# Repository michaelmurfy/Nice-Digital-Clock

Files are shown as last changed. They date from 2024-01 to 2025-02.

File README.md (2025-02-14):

# Digital Clock Hardware
This is a fork from the original project with 3 main goals:
- Fix automatic DST time.
- Add the ability to change the NTP server.
- Smoother automatic brightness.

I also recreated the web interface to be a little cleaner using Bootstrap. Functionality remains the same outside of that.

## Notice:
There is a hardware change between the 8 clocks sold on Tindie and these. The original production clocks from tindie are:  
- Missing a copper trace between the 3v3 line and the 3v3 output of the LDO. This is corrected with a hand-assembled solder bridge.  
- The I2C lines are shifted right by one pin. The tindie version uses GPIO21 for SDA and GPIO33 for SCL.  
- The Tindie clocks have a manually soldered bodge to move one of the binary coded digits off GPIO 46, which is an input only strapping pin.

## Description
This is an internet connected Clock which synchronizes with NTP servers to perpetually serve an accurate time. It is unable to keep very good time by itself. As such, it requires a stable, consistent network connection to show reliable time. With that, it should always be acctute within a second or so. To improve accuracy, you could modify the firmware to check every hour or half hour instead of once per day.  

It's built using BCD Decoders and 1.5" Seven segment displays for a nice clean look. It also utilizes an ambient light sensor to automatically brighten and dim to match the room light.  

This clock serves it's own webpage for configuration. Upon first boot, it activates an access point ssid `NiceClock`, password `MinesBigger`. Connect to the default gateway `192.168.4.1` to configure the clock and provide network credentials. Once credentials are provided, it should instantly connect and acquire the network time.  
To view the device's IP address, press the boot button on the rear.

## Hacking
This device openly exposes both a TTL UART and JTAG port on the rear of the board, near the ESP Module. You can also use the USB Port to program and upload code. While holding the boot button, then press reset. This enters the ESP32 into bootloader mode, and allows you to reflash new firmware or filesystem to the device.

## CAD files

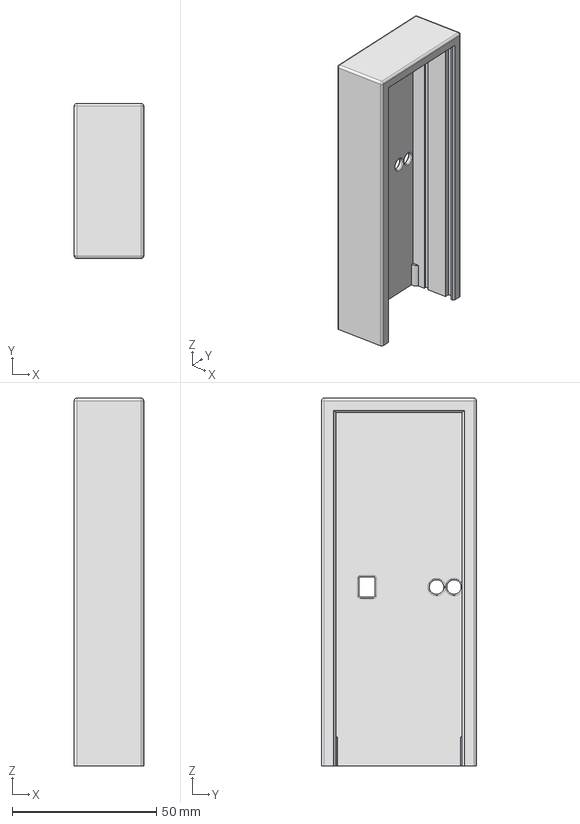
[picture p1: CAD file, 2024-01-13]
Case/V2.1 Case.stp
24.1 x 53.8 x 127.5 mm

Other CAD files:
Case/V2.1 Case.ipt
Case/V2.1 Case.stl

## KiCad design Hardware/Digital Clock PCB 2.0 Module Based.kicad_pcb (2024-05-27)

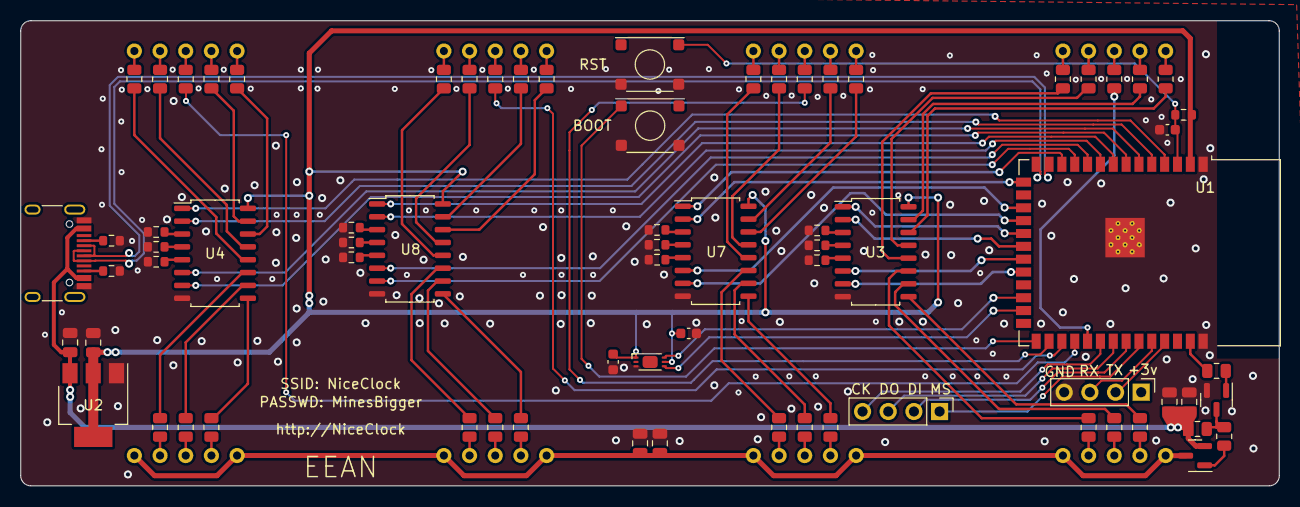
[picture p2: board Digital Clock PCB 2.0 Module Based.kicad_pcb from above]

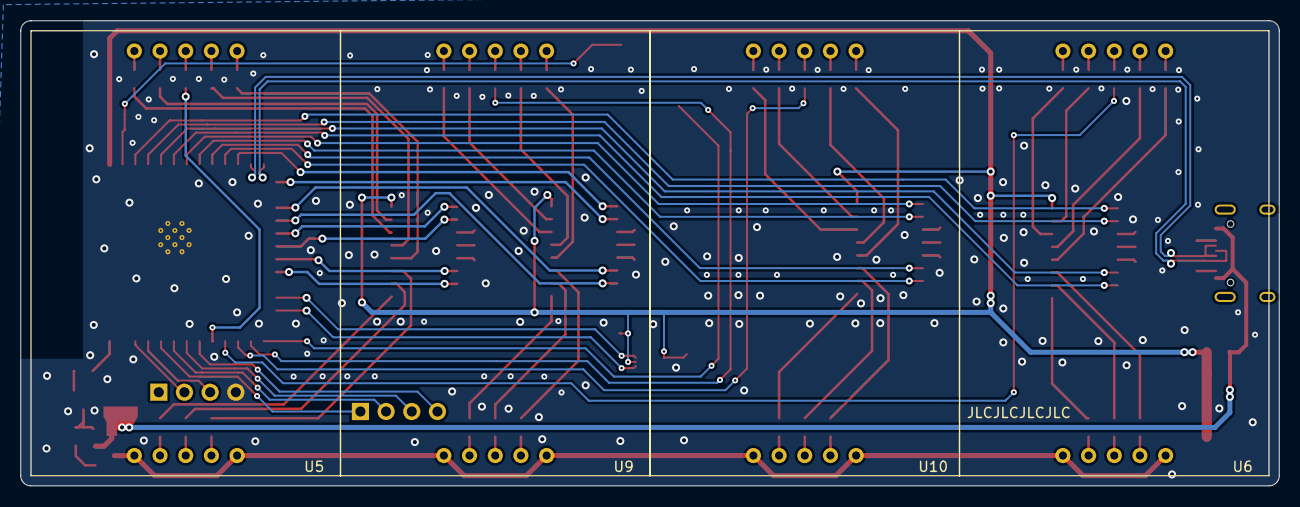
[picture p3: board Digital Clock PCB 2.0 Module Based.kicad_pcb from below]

Board: 2 copper layers, 124.5 x 46.0 mm, 77 parts (4 on the bottom side), 114 nets.

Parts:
C1, C2: 10u; C_0805_2012Metric
C3, C4, C5: 100n; C_0603_1608Metric
C6, C7, C8, C9: C; C_0805_2012Metric
J1: USB_C_Receptacle_USB2.0; USB_C_Receptacle_HRO_TYPE-C-31-M-12
J2, J3: Conn_01x04; PinHeader_1x04_P2.54mm_Vertical
PD1: BH1730; WSOF6
Q1: C15127; SOT-23
Q2: C8545; SOT-23
R1, R2: 5k1; R_0603_1608Metric
R3: 10k; R_0603_1608Metric
R4, R5, R6: 47k; R_0805_2012Metric
R7, R8, R9, R10, R11, R12, R29, R30, R31, R32, R33, R34: R; R_0603_1608Metric
R13, R14, R15, R16, R17, R18, R19, R21, R22, R23, R24, R25, R26, R27, R35, R36, R37, R38, R39, R40, R41, R43, R44, R45, R46, R47, R48, R49: 100; R_0805_2012Metric
R20, R28, R42, R50: 1000; R_0805_2012Metric
SW1, SW2: SW_Push; 5.2mm_Tactile_Push_Button
U1: ESP32-S2-SOLO-2; ESP32-S3-WROOM-1
U2: AMS1117-3.3; SOT-223-3_TabPin2
U3, U4, U7, U8: 74LS47; SOIC-16_4.55x10.3mm_P1.27mm
U5, U6, U9, U10: SBC18-11SURKCGKWA; Segment_Display_1-5_inch

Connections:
+3V3: C2.1, C4.1, C5.1, PD1.1 (VCC), PD1.5 (DVI), R3.2, U1.2 (VCC), U2.2 (VO), U3.16 (VCC), U4.16 (VCC), U7.16 (VCC), U8.16 (VCC)
A1: U1.7 (IO7), U4.7 (A)
A2: U1.11 (IO18), U8.7 (A)
A3: U1.18 (IO10), U7.7 (A)
A4: U1.22 (IO14), U3.7 (A)
B1: U1.4 (IO4), U4.1 (B)
B2: U1.8 (IO15), U8.1 (B)
B3: U1.12 (IO8), U7.1 (B)
B4: U1.19 (IO11), U3.1 (B)
C1: U1.5 (IO5), U4.2 (C)
C2: U1.9 (IO16), U8.2 (C)
C3: U1.15 (IO3), U7.2 (C)
C4: U1.20 (IO12), U3.2 (C)
CC: C8.1, C9.1, Q1.3 (D), U5.1 (CC), U5.5 (CC), U6.1 (CC), U6.5 (CC), U9.1 (CC), U9.5 (CC), U10.1 (CC), U10.5 (CC)
D1: U1.6 (IO6), U4.6 (D)
D2: U1.10 (IO17), U8.6 (D)
D3: U1.17 (IO9), U7.6 (D)
D4: U1.21 (IO13), U3.6 (D)
D+: J1.A6 (D+), J1.B6 (D+), U1.14 (IO20)
D-: J1.A7 (D-), J1.B7 (D-), U1.13 (IO19)
GND: C1.2, C2.2, C3.2, C4.2, C5.2, C6.2, C7.2, C8.2, C9.2, J1.A1 (GND), J1.A12 (GND), J1.B1 (GND), J1.B12 (GND), J2.4, PD1.3 (GND), Q2.2 (S), R1.2, R2.2, R7.1, R8.1, R9.1, R10.1, R11.1, R12.1, R29.1, R30.1, R31.1, R32.1, R33.1, R34.1, SW1.2, SW2.2, U1.1 (GND), U1.40 (GND), U1.41 (EPAD), U2.1 (GND), U3.8 (GND), U4.8 (GND), U7.8 (GND), U8.8 (GND)
IO35: R42.1, U1.28 (IO35)
IO36: R50.1, U1.29 (IO36)
IO37: R28.1, U1.30 (IO37)
IO38: R20.1, U1.31 (IO38)
LED: R4.2, U1.39 (IO1)
unnamed: J1.A5 (CC1), R1.1
unnamed: J1.B5 (CC2), R2.1
unnamed: Q1.1 (G), R5.1
unnamed: Q2.3 (D), R5.2, R6.1
unnamed: Q2.1 (G), R4.1
unnamed: SW1.1, U1.27 (IO0)
unnamed: R8.2, U3.4 (BI)
unnamed: R7.2, U3.3 (LT)
unnamed: R9.2, U3.5 (RBI)
unnamed: R13.1, U3.13 (a)
unnamed: R14.1, U3.12 (b)
unnamed: R15.1, U3.11 (c)
unnamed: R16.1, U3.10 (d)
unnamed: R17.1, U3.9 (e)
unnamed: R18.1, U3.15 (f)
unnamed: R19.1, U3.14 (g)
unnamed: R11.2, U4.4 (BI)
unnamed: R10.2, U4.3 (LT)
unnamed: R12.2, U4.5 (RBI)
unnamed: R21.1, U4.13 (a)
unnamed: R22.1, U4.12 (b)
unnamed: R23.1, U4.11 (c)
unnamed: R24.1, U4.10 (d)
unnamed: R25.1, U4.9 (e)
unnamed: R26.1, U4.15 (f)
unnamed: R27.1, U4.14 (g)
unnamed: R13.2, U5.7 (A)
unnamed: R14.2, U5.6 (B)
unnamed: R15.2, U5.4 (C)
unnamed: R16.2, U5.3 (D)
unnamed: R20.2, U5.8 (DP)
unnamed: R17.2, U5.2 (E)
unnamed: R18.2, U5.9 (F)
unnamed: R19.2, U5.10 (G)
unnamed: R21.2, U6.7 (A)
unnamed: R22.2, U6.6 (B)
unnamed: R23.2, U6.4 (C)
unnamed: R24.2, U6.3 (D)
unnamed: R28.2, U6.8 (DP)
unnamed: R25.2, U6.2 (E)
unnamed: R26.2, U6.9 (F)
unnamed: R27.2, U6.10 (G)
unnamed: R33.2, U7.4 (BI)
unnamed: R32.2, U7.3 (LT)
unnamed: R34.2, U7.5 (RBI)
unnamed: R35.1, U7.13 (a)
unnamed: R36.1, U7.12 (b)
unnamed: R37.1, U7.11 (c)
unnamed: R38.1, U7.10 (d)
unnamed: R39.1, U7.9 (e)
unnamed: R40.1, U7.15 (f)
unnamed: R41.1, U7.14 (g)
unnamed: R30.2, U8.4 (BI)
unnamed: R29.2, U8.3 (LT)
unnamed: R31.2, U8.5 (RBI)
unnamed: R43.1, U8.13 (a)
unnamed: R44.1, U8.12 (b)
unnamed: R45.1, U8.11 (c)
unnamed: R46.1, U8.10 (d)
unnamed: R47.1, U8.9 (e)
unnamed: R48.1, U8.15 (f)
unnamed: R49.1, U8.14 (g)
unnamed: R35.2, U9.7 (A)
unnamed: R36.2, U9.6 (B)
unnamed: R37.2, U9.4 (C)
unnamed: R38.2, U9.3 (D)
unnamed: R42.2, U9.8 (DP)
unnamed: R39.2, U9.2 (E)
unnamed: R40.2, U9.9 (F)
unnamed: R41.2, U9.10 (G)
unnamed: R43.2, U10.7 (A)
unnamed: R44.2, U10.6 (B)
unnamed: R45.2, U10.4 (C)
unnamed: R46.2, U10.3 (D)
unnamed: R50.2, U10.8 (DP)
unnamed: R47.2, U10.2 (E)
unnamed: R48.2, U10.9 (F)
unnamed: R49.2, U10.10 (G)
RST: C3.1, R3.1, SW2.1, U1.3 (EN)
RX: J2.3, U1.36 (RX)
SCL: PD1.6 (SCL), U1.24 (IO33)
SDA: PD1.4 (SDA), U1.25 (IO34)
TCK: J3.4, U1.32 (IO39)
TDI: J3.2, U1.34 (IO41)
TDO: J3.3, U1.33 (IO40)
TMS: J3.1, U1.35 (IO42)
TX: J2.2, U1.37 (TX)
VBUS: C1.1, C6.1, C7.1, J1.A4 (VBUS), J1.A9 (VBUS), J1.B4 (VBUS), J1.B9 (VBUS), J2.1, Q1.2 (S), R6.2, U2.3 (VI)

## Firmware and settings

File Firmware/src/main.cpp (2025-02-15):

#include <Arduino.h>
#include <WiFi.h>
#include <Preferences.h>
#include <AsyncUDP.h>
#include <ESPAsyncWebServer.h>
#include <SPIFFS.h>
#include <Wire.h>
#include <NTPClient.h>
#include <time.h>
#include <movingAvg.h>

// Prototypes:
uint8_t readAmbientLightData();
static void IRAM_ATTR showIPFlag();
void updateBrightnessSmooth();

// User Memory for WiFi/clock configuration.
Preferences preferences;

// Access Point Credentials.
const char* APID = "NiceClock";
const char* APSK = "MinesBigger";
const char* GARBAGE_STRING = "C!pbujKY2#4HXbcm5dY!WJX#ns29ff#vEDWmbZ9^d!QfBW@o%Trfj&sPENuVe&sx";

// Global variables.
bool softAPActive = false;
bool showIP = false;

// Server Stuff.
WiFiUDP ntpUDP;
NTPClient timeClient(ntpUDP);  // Uses default server ("time.cloudflare.com") initially; can be updated.
AsyncWebServer server(80);

// PWM properties for brightness control.
#define freq 2000
#define ledChannel 0
#define ledPWMResolution 8

// Pins for 7-segment displays.
const int hours_pin[8]   = {10, 8, 3, 9, 14, 11, 12, 13};
const int minutes_pin[8] = {7, 4, 5, 6, 18, 15, 16, 17};

// Additional control pins.
const int ledPin = 1;       // Power pin for segment displays (common anode)
const int decimalPin = 35;  // Decimal point separating hours and minutes
// Other decimal points on pins 36, 37, 38.

// ----- Brightness Smoothing Variables -----
// We accumulate ambient light readings over 500ms, then interpolate from the previous PWM value to the new target over that 500ms period.
uint8_t currentPWM = 50;
unsigned long lastAvgTime = 0;
unsigned long transitionStartTime = 0;
uint8_t prevPWM = 50;
uint8_t targetPWM = 50;
uint32_t lightSum = 0;
uint16_t sampleCount = 0;

// Create moving average object for ambient light (if desired).
movingAvg ambientLight(10);

// ----- Function: readAmbientLightData -----
// Reads the BH1730 sensor data and maps it between the stored min and max brightness values.
uint8_t readAmbientLightData() {
  Wire.beginTransmission(0x29);
  Wire.write(0b10010100);
  Wire.endTransmission();
  Wire.requestFrom(0x29, 2);
  byte highByte = Wire.read();
  byte lowByte = Wire.read();
  int lightLevel = (highByte << 8) | lowByte;
  return map(lightLevel, 0, 65535, preferences.getInt("minBrightness", 10), preferences.getInt("maxBrightness", 255));
}

// ----- Function: showIPFlag -----
// Interrupt handler: sets flag so that the IP will be displayed.
static void IRAM_ATTR showIPFlag() {
  showIP = true;
}

// ----- Function: updateBrightnessSmooth -----
// Accumulates ambient light readings over 500ms, computes an average,
// then linearly interpolates the PWM output from the previous value to the new target over 500ms.
void updateBrightnessSmooth() {
  unsigned long now = millis();
  uint8_t reading = ambientLight.reading(readAmbientLightData());
  lightSum += reading;
  sampleCount++;
  
  if (now - lastAvgTime >= 500) {
    uint8_t avgPWM = sampleCount ? (lightSum / sampleCount) : reading;
    lastAvgTime = now;
    lightSum = 0;
    sampleCount = 0;
    prevPWM = currentPWM;
    targetPWM = avgPWM;
    transitionStartTime = now;
  }
  
  uint32_t elapsed = now - transitionStartTime;
  if (elapsed < 500) {
    float fraction = (float)elapsed / 500.0;
    uint8_t newPWM = prevPWM + (int)((targetPWM - prevPWM) * fraction);
    ledcWrite(ledChannel, newPWM);
    currentPWM = newPWM;
  } else {
    ledcWrite(ledChannel, targetPWM);
    currentPWM = targetPWM;
  }
}

// ----- Function: printTime -----
// Splits hours and minutes into tens and ones and writes the bits to the display pins.
void printTime(int hours, int minutes) {
  bool timeFormat = preferences.getBool("timeFormat", 1);
  if (!timeFormat) {
    hours = (hours % 12) ?: 12;
  }
  int hoursT = hours / 10;
  int hoursO = hours % 10;
  int minutesT = minutes / 10;
  int minutesO = minutes % 10;
  
  digitalWrite(hours_pin[4], (hoursT >> 0) & 1);
  digitalWrite(hours_pin[5], (hoursT >> 1) & 1);
  digitalWrite(hours_pin[6], (hoursT >> 2) & 1);
  digitalWrite(hours_pin[7], (hoursT >> 3) & 1);
  
  digitalWrite(hours_pin[0], (hoursO >> 0) & 1);
  digitalWrite(hours_pin[1], (hoursO >> 1) & 1);
  digitalWrite(hours_pin[2], (hoursO >> 2) & 1);
  digitalWrite(hours_pin[3], (hoursO >> 3) & 1);
  
  digitalWrite(minutes_pin[4], (minutesT >> 0) & 1);
  digitalWrite(minutes_pin[5], (minutesT >> 1) & 1);
  digitalWrite(minutes_pin[6], (minutesT >> 2) & 1);
  digitalWrite(minutes_pin[7], (minutesT >> 3) & 1);
  
  digitalWrite(minutes_pin[0], (minutesO >> 0) & 1);
  digitalWrite(minutes_pin[1], (minutesO >> 1) & 1);
  digitalWrite(minutes_pin[2], (minutesO >> 2) & 1);
  digitalWrite(minutes_pin[3], (minutesO >> 3) & 1);
}

// ----- Function: displayIP -----
// Displays the IP address on the display by showing each octet in turn.
void displayIP(IPAddress localIP) {
  pinMode(38, OUTPUT);
  digitalWrite(decimalPin, 1);
  digitalWrite(38, 0);
  
  int octet0 = localIP[0];
  int octet1 = localIP[1];
  int octet2 = localIP[2];
  int octet3 = localIP[3];
  
  printTime(octet0 / 100, octet0 % 100);
  delay(1500);
  printTime(octet1 / 100, octet1 % 100);
  delay(1500);
  printTime(octet2 / 100, octet2 % 100);
  delay(1500);
  printTime(octet3 / 100, octet3 % 100);
  delay(1500);
  
  digitalWrite(decimalPin, 0);
  pinMode(38, INPUT);
}

void setup() {
  Serial.begin(9600);
  Serial.println("Setup started");
  preferences.begin("usermem");
  SPIFFS.begin();
  
  // Set the timezone from preferences.
  setenv("TZ", preferences.getString("timezone", "UTC").c_str(), 1);
  tzset();
  
  // Setup PWM for brightness.
  ledcSetup(ledChannel, freq, ledPWMResolution);
  ledcAttachPin(ledPin, ledChannel);
  ledcWrite(ledChannel, 50);
  
  // Initialize I2C on pins SDA=34, SCL=33.
  Wire.begin(34, 33);
  // Initialize ambient light sensor.
  Wire.beginTransmission(0x29);
  Wire.write(0x80);
  Wire.write(0x3);
  Wire.endTransmission();
  
  ambientLight.begin();
  // Perform several dummy readings.
  for (int i = 0; i < 10; i++) {
    readAmbientLightData();
  }
  
  pinMode(decimalPin, OUTPUT);
  digitalWrite(decimalPin, 0);
  for (int i = 0; i < 8; i++) {
    pinMode(hours_pin[i], OUTPUT);
    pinMode(minutes_pin[i], OUTPUT);
  }
  
  // ----- WiFi Setup -----
  Serial.println("Starting Access Point");
  WiFi.softAPsetHostname("niceclock");
  WiFi.mode(WIFI_AP_STA);
  WiFi.softAP(APID, APSK);
  softAPActive = true;
  
  if (preferences.getString("WiFiSSID", GARBAGE_STRING) == GARBAGE_STRING ||
      preferences.getString("WiFiPSK", GARBAGE_STRING) == GARBAGE_STRING) {
    Serial.println("WiFi not configured. Skipping connection.");
  } else {
    Serial.println("WiFi configured. Attempting connection.");
    WiFi.setHostname("niceclock");
    WiFi.begin(preferences.getString("WiFiSSID", GARBAGE_STRING).c_str(),
               preferences.getString("WiFiPSK", GARBAGE_STRING).c_str());
    while(!WiFi.isConnected() && millis() < 5000) {
      Serial.print(". ");
      delay(100);
    }
    Serial.println();
    if (WiFi.isConnected()){
      Serial.println("Connection successful. Tearing down AP.");
      WiFi.softAPdisconnect();
      WiFi.mode(WIFI_STA);
      softAPActive = false;
      displayIP(WiFi.localIP());
    } else {
      Serial.println("Connection failed. Use web portal to enter credentials.");
    }
  }
  
  digitalWrite(decimalPin, 0);
  
  timeClient.begin();
  timeClient.update();
  
  // ----- Web Configuration Endpoints -----
  server.on("/", HTTP_GET, [](AsyncWebServerRequest *request){
    if(!SPIFFS.exists("/index.html")){
      request->send(404, "text/plain", "File not found");
      return;
    }
    request->send(SPIFFS, "/index.html", "text/html");
  });
  
  server.on("/zones.csv", HTTP_GET, [](AsyncWebServerRequest *request){
    request->send(SPIFFS, "/zones.csv", "text/csv");
  });
  
  server.on("/updateWiFi", HTTP_POST, [](AsyncWebServerRequest *request){
    if(request->hasParam("ssid", true) && request->hasParam("psk", true)){
      String ssid = request->getParam("ssid", true)->value();
      String psk = request->getParam("psk", true)->value();
      if(ssid != ""){
        Serial.println("Updating WiFi: " + ssid);
        preferences.putString("WiFiSSID", ssid);
        preferences.putString("WiFiPSK", psk);
        WiFi.setHostname("niceclock");
        WiFi.begin(preferences.getString("WiFiSSID", GARBAGE_STRING).c_str(),
                   preferences.getString("WiFiPSK", GARBAGE_STRING).c_str());
      }
    }
    request->send(200, "text/plain", "WiFi credentials updated");
  });
  
  server.on("/updateTimeFormat", HTTP_POST, [](AsyncWebServerRequest *request) {
    if(request->hasArg("isChecked")){
      String isChecked = request->arg("isChecked");
      preferences.putBool("timeFormat", (isChecked == "true") ? 0 : 1);
    }
    request->send(200, "text/plain", "Time format updated");
  });
  
  server.on("/updateBrightness", HTTP_POST, [](AsyncWebServerRequest *request){
    if(request->hasParam("minBrightnessSlider", true) && request->hasParam("maxBrightnessSlider", true)){
      int minVal = request->getParam("minBrightnessSlider", true)->value().toInt();
      int maxVal = request->getParam("maxBrightnessSlider", true)->value().toInt();
      preferences.putInt("minBrightness", minVal);
      preferences.putInt("maxBrightness", maxVal);
    }
    request->send(200, "text/plain", "Brightness limits updated");
  });
  
  server.on("/setTZ", HTTP_POST, [](AsyncWebServerRequest *request){
    if(request->hasArg("timezone")){
      String timezone = request->arg("timezone");
      preferences.putString("timezone", timezone);
      configTzTime(timezone.c_str(), "time.cloudflare.com");
      timeClient.update();
    }
    request->send(200, "text/plain", "Timezone updated");
  });
  
  server.on("/updateNTP", HTTP_POST, [](AsyncWebServerRequest *request){
    if(request->hasArg("ntpServer")){
      String newNtp = request->arg("ntpServer");
      timeClient = NTPClient(ntpUDP, newNtp.c_str());
      timeClient.begin();
      timeClient.update();
      request->send(200, "text/plain", "NTP server updated to " + newNtp);
    } else {
      request->send(400, "text/plain", "Missing ntpServer parameter");
    }
  });
  
  server.onNotFound([](AsyncWebServerRequest *request){
    String path = request->url();
    if (path.endsWith("/")) path += "index.html";
    String contentType = "text/plain";
    if (path.endsWith(".html")) contentType = "text/html";
    else if (path.endsWith(".css")) contentType = "text/css";
    else if (path.endsWith(".csv")) contentType = "text/csv";
    if(SPIFFS.exists(path)){
      request->send(SPIFFS, path, contentType);
    } else {
      request->send(404, "text/plain", "File not found");
    }
  });
  
  server.begin();
  
  attachInterrupt(digitalPinToInterrupt(0), showIPFlag, FALLING);
}

void loop() {
  if(softAPActive && WiFi.isConnected()){
    Serial.println("Internet Connected. Tearing down AP.");
    WiFi.softAPdisconnect();
    WiFi.mode(WIFI_STA);
    softAPActive = false;
    timeClient.update();
  }
  if(!softAPActive && !WiFi.isConnected()){
    Serial.println("Lost Internet. Restarting AP.");
    WiFi.softAPsetHostname("niceclock");
    WiFi.mode(WIFI_AP_STA);
    WiFi.softAP(APID, APSK);
    softAPActive = true;
  }
  if((timeClient.getHours() % 6) == 0 &&
     timeClient.getMinutes() == 0 &&
     timeClient.getSeconds() == 0){
    timeClient.update();
    delay(1000);
  }
  
  time_t now = timeClient.getEpochTime();
  struct tm *timeinfo = localtime(&now);
  printTime(timeinfo->tm_hour, timeinfo->tm_min);
  
  updateBrightnessSmooth();
  
  if (showIP){
    displayIP(WiFi.localIP());
    showIP = false;
  }
}

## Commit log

2024-01-13 Add cutout for antenna in case
    [V2.0 Case.ipt, V2.0 Case.stl, V2.0 Case.stp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]
2024-01-17 Revert main.cpp to real release code
    [main.cpp]
2024-05-19 Move firmware down a directory. Add Integration test. Requires gitignored file containing wifi credentials.
    [Digital Clock PCB 2.0 Module Based.kicad_pcb, zones.csv]
2024-05-27 Updates to layout, keep production files off github
    [Digital Clock PCB 2.0 Module Based.kicad_pcb]
2025-02-14 Updating Firmware to fix DST bug
    [zones.csv]
